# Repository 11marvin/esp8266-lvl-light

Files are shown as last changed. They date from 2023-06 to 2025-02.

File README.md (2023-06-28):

# ESP8266 LVL Light Control Board

This project contains the KiCad design files for a replacement control board used to control the LVL ceiling light (https://templates.blakadder.com/lvl_300.html) with additional features such as brightness adjustment, colour temperature control (CCT) and Wi-Fi connectivity. The board also includes provisions for connecting an I2C bus, a GPIO and power supply (3V3, GND).

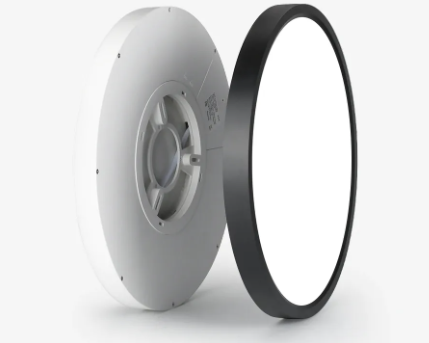
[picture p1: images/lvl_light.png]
LVL Ceiling Light


## Features

- Control LVL ceiling light using ESP8266-12F
- Adjust brightness and color temperature (CCT)
- Wi-Fi connectivity for remote control and automation
- I2C bus and GPIO for additional device integration

## Board

32 mm x 20 mm (without antenna overlap)

### Front
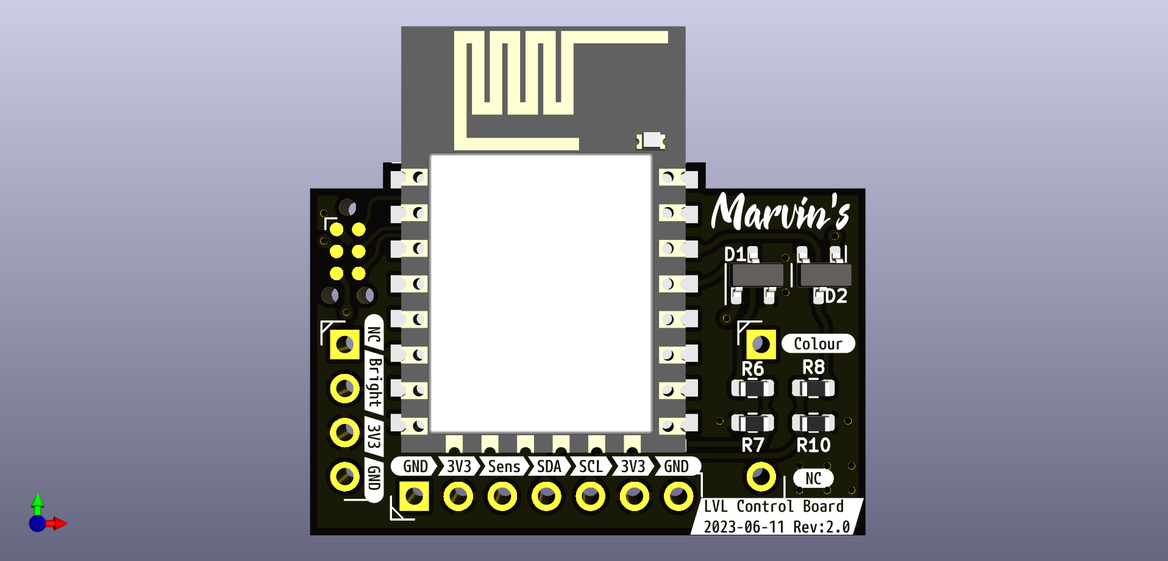
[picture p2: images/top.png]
Front side


### Back
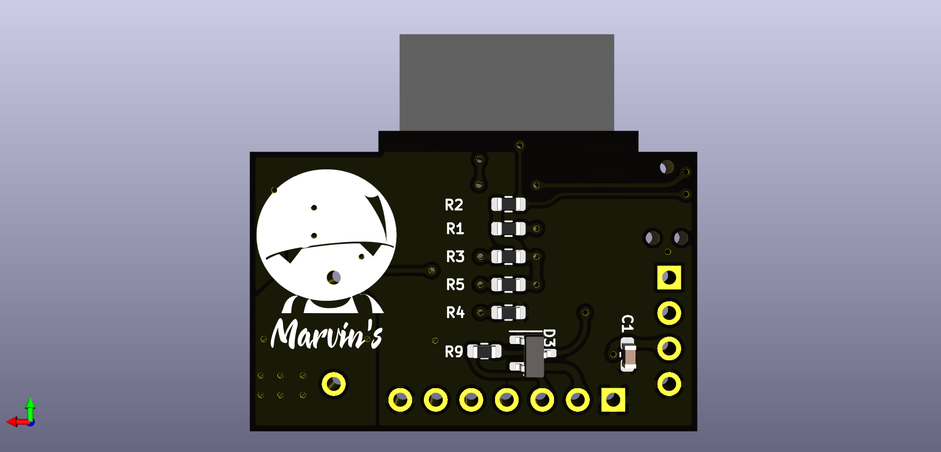
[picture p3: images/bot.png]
Back side


## Contributing

Contributions are welcome! If you find any issues or have suggestions for improvements, please open an issue or submit a pull request.

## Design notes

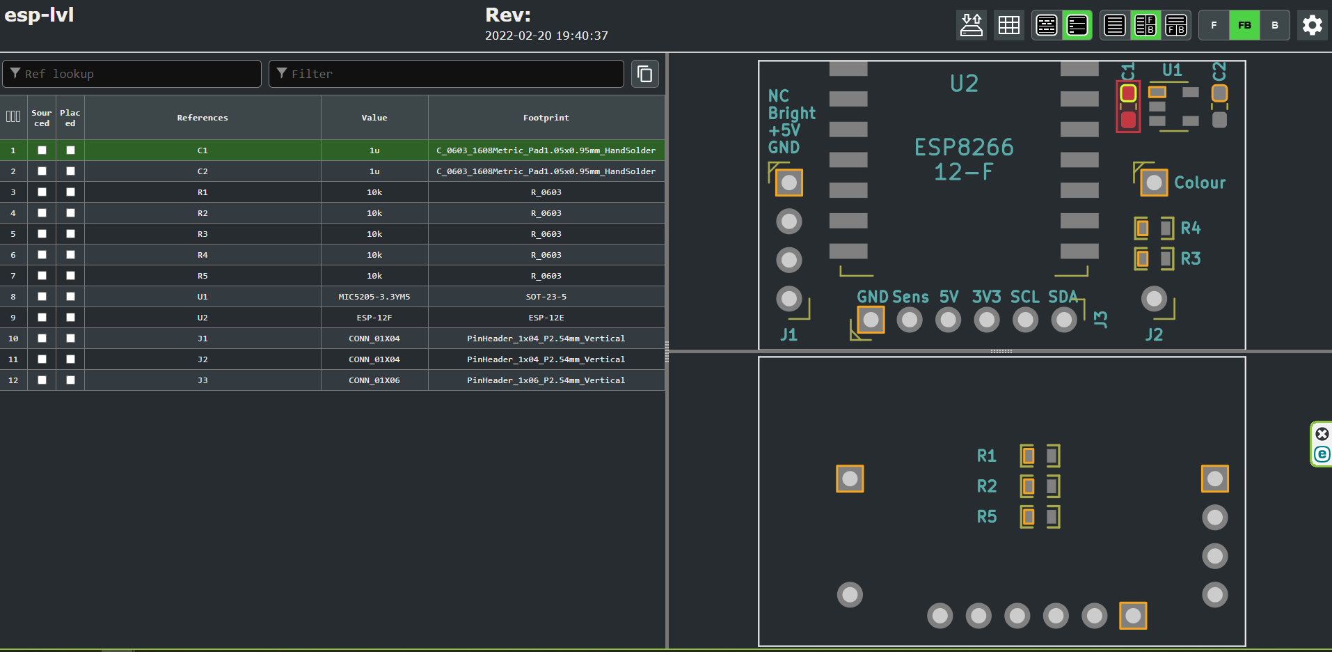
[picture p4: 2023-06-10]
Documentation/Board.png

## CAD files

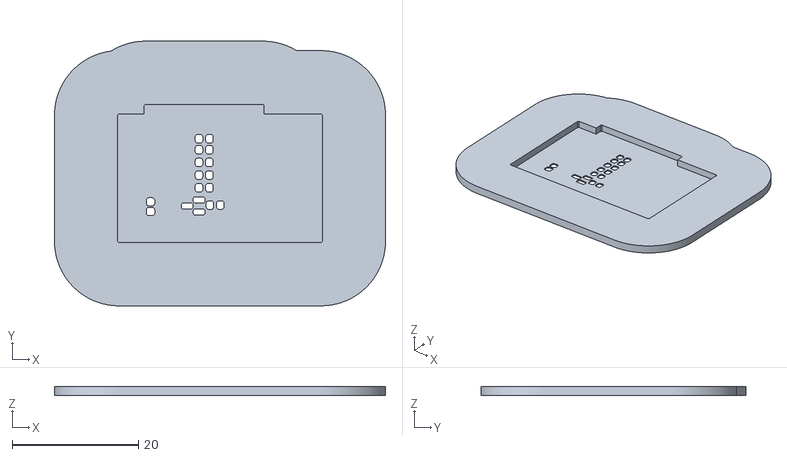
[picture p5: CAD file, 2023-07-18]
Fabrication/STL/bottomStencil.stl
52.4 x 41.9 x 1.50

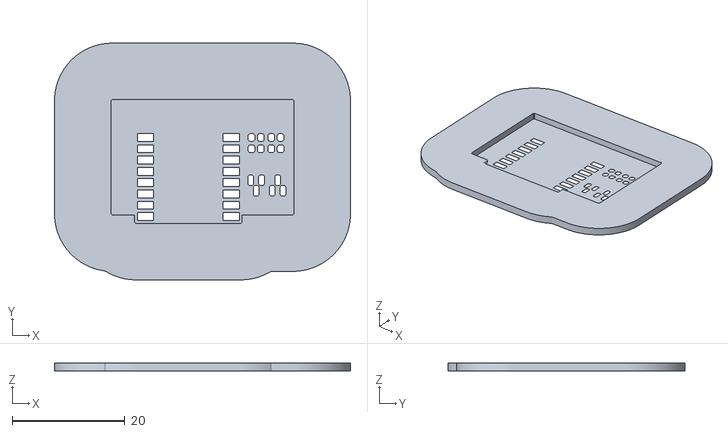
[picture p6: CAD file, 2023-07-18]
Fabrication/STL/topStencil.stl
52.4 x 41.9 x 1.50

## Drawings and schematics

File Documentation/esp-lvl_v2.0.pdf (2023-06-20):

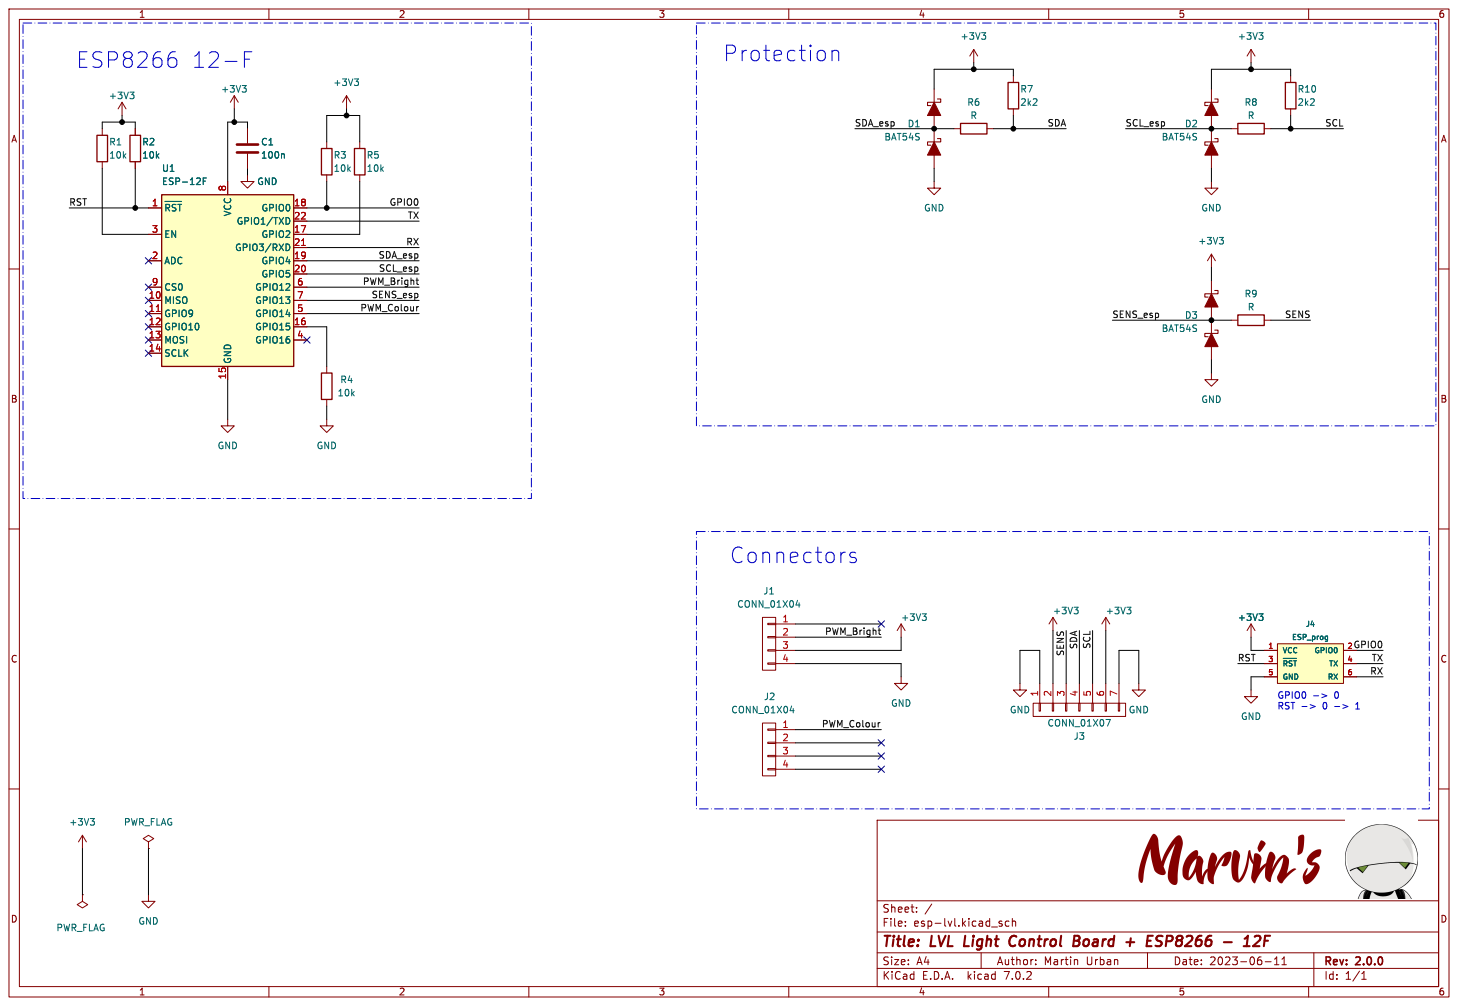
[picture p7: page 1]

Id: 1/1 Title: LVL Light Control Board + ESP8266 - 12F

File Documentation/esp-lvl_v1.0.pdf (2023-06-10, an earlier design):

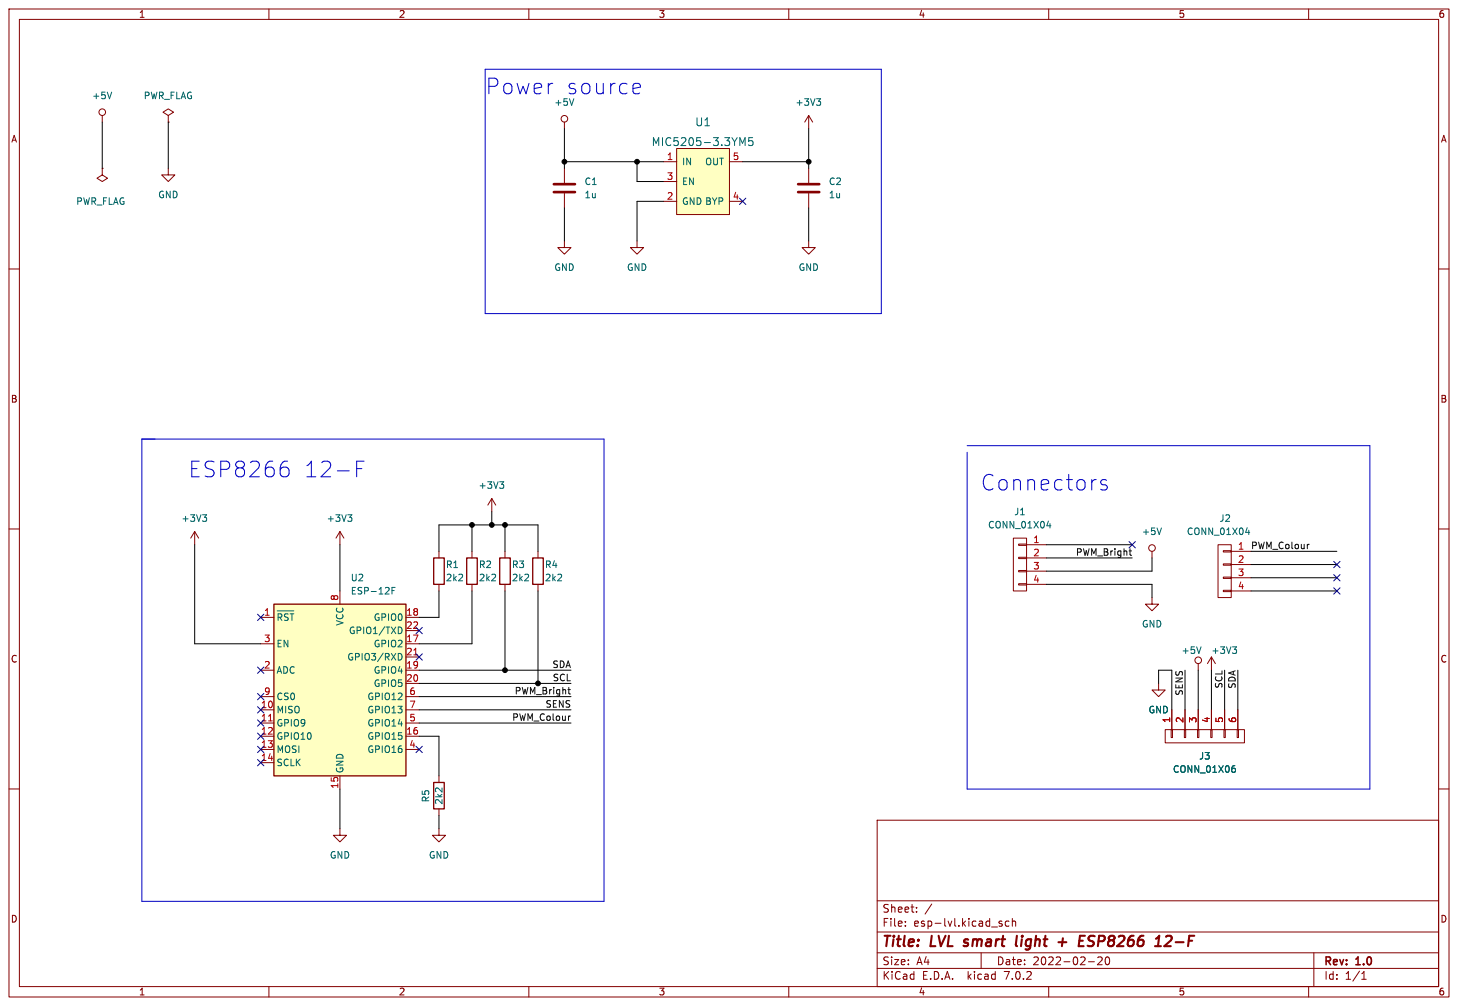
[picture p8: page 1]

Id: 1/1 Title: LVL smart light + ESP8266 12-F

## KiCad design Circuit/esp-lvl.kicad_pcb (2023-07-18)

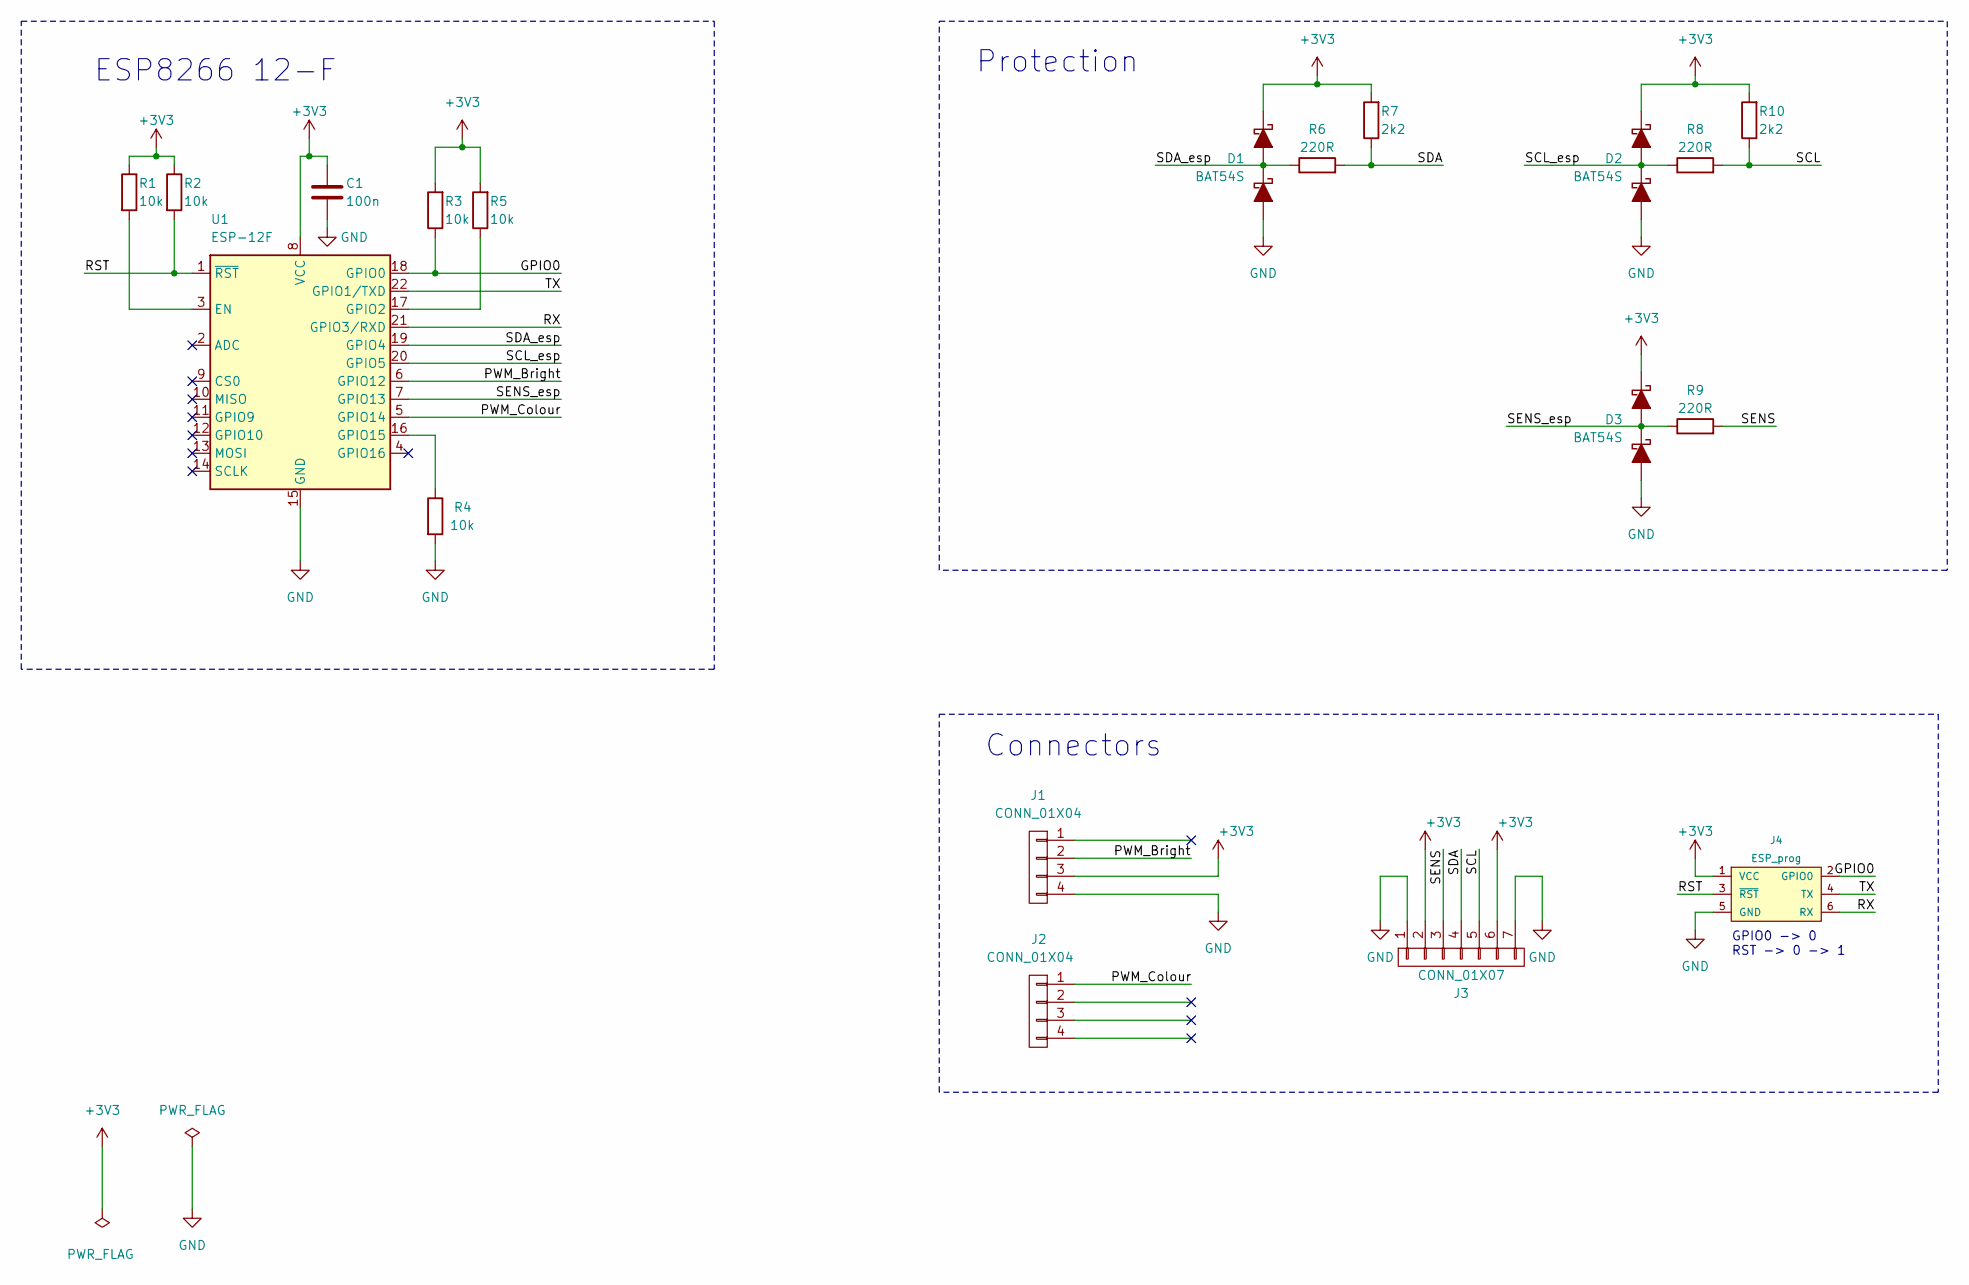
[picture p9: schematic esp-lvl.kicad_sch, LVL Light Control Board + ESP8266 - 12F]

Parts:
C1: 100n; C_0603_1608Metric
D1, D2, D3: BAT54S; SOT-23
J1, J2: CONN_01X04; PinHeader_1x04_P2.54mm_Vertical
J3: CONN_01X07; PinHeader_1x07_P2.54mm_Vertical
J4: ESP_prog; Tag-Connect_TC2030-IDC-NL
R1, R2, R3, R4, R5: 10k; R_0603_1608Metric
R6, R8, R9: 220R; R_0603_1608Metric
R7, R10: 2k2; R_0603_1608Metric
U1: ESP-12F; ESP-12E

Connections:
+3V3: C1.1, D1.2 (C), D2.2 (C), D3.2 (C), J1.3, J3.2, J3.6, J4.1 (VCC), R1.1, R2.1, R3.2, R5.2, R7.2, R10.2, U1.8 (VCC)
/GPIO0: J4.2 (GPIO0), R3.1, U1.18 (GPIO0)
/PWM_Bright: J1.2, U1.6 (GPIO12)
/PWM_Colour: J2.1, U1.5 (GPIO14)
/RST: J4.3 (~RST), R2.2, U1.1 (~RST)
/RX: J4.6 (RX), U1.21 (GPIO3/RXD)
/SCL: J3.5, R8.2, R10.1
/SCL_esp: D2.3 (C), R8.1, U1.20 (GPIO5)
/SDA: J3.4, R6.2, R7.1
/SDA_esp: D1.3 (C), R6.1, U1.19 (GPIO4)
/SENS: J3.3, R9.2
/SENS_esp: D3.3 (C), R9.1, U1.7 (GPIO13)
/TX: J4.4 (TX), U1.22 (GPIO1/TXD)
GND: C1.2, D1.1 (A), D2.1 (A), D3.1 (A), J1.4, J3.1, J3.7, J4.5 (GND), R4.2, U1.15 (GND)
unnamed: R1.2, U1.3 (EN)
unnamed: R5.1, U1.17 (GPIO2)
unnamed: R4.1, U1.16 (GPIO15)

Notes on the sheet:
Connectors
GPIO0 -> 0 RST -> 0 -> 1
Protection
ESP8266 12-F

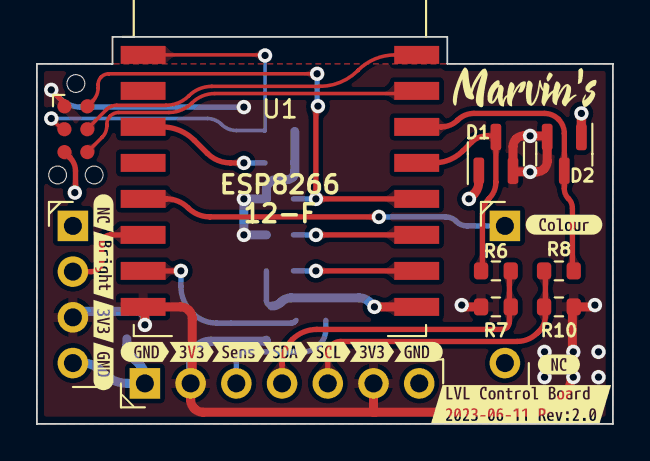
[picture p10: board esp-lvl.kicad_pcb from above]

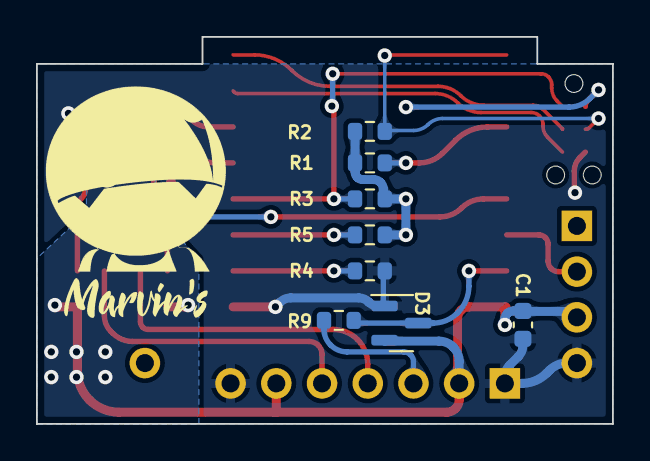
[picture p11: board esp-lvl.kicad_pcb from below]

Board: 2 copper layers, 32.0 x 21.5 mm, 35 parts (9 on the bottom side), 17 nets.

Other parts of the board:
kibuzzard-6485D4C1: G***; kibuzzard-6485D4C1
kibuzzard-6485EB90: G***; kibuzzard-6485EB90
kibuzzard-64859B50: G***; kibuzzard-64859B50
kibuzzard-648599E7: G***; kibuzzard-648599E7
kibuzzard-6485947F: G***; kibuzzard-6485947F
kibuzzard-6485998B: G***; kibuzzard-6485998B
kibuzzard-64859500, kibuzzard-64859500#2: G***; kibuzzard-64859500
kibuzzard-64859549: G***; kibuzzard-64859549
kibuzzard-64859551: G***; kibuzzard-64859551
kibuzzard-64859557: G***; kibuzzard-64859557
kibuzzard-64859561: G***; kibuzzard-64859561
kibuzzard-64859916: G***; kibuzzard-64859916
kibuzzard-64859921: G***; kibuzzard-64859921
kibuzzard-64859928: G***; kibuzzard-64859928
kibuzzard-64860007: G***; kibuzzard-64860007

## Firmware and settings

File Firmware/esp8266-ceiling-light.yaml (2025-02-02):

substitutions:
  devicename: "ceiling-light"
  friendly_name: "Ceiling Light"

esphome:
  platform: ESP8266
  board: esp12e

  name: ${devicename}
  friendly_name: ${friendly_name}
  name_add_mac_suffix: True

  comment: Dimmable ceiling light with CCT and motion detector.
  project:
    name: Marvin's.${friendly_name}
    version: "1.0.3"

  on_boot:
    - script.execute: offline_light

dashboard_import:
  package_import_url: github://11marvin/esp8266-lvl-light/Firmware/esp8266-ceiling-light.yaml@master

wifi:

  # Enable fallback hotspot (captive portal) in case wifi connection fails
  ap: {} # This spawns an AP with the device name and mac address with no password.

web_server:
  port: 80
  
captive_portal:

# Enable logging
logger:

# Enable Home Assistant API
api:

# Enable Home Assistant OTA
ota:
  platform: esphome


script:
  - id: offline_light
    mode: restart     # Light will be kept on during 10 minutes since
                      # the latest time the script is executed
    then:
      - light.turn_on:
          id: mylight 
          brightness: 90%
          color_temperature: 3900K
      - delay: 10 min
      - light.turn_off: mylight

sensor:
  - platform: wifi_signal
    name: WiFi Signal
    update_interval: 60s

binary_sensor:
  - platform: gpio
    id: motion
    pin:
      number: GPIO13
    name: motion
    device_class: motion
    on_press:
      - while:
          condition:
            binary_sensor.is_on: motion
          then:
            - if:
                condition:
                  not:
                    api.connected:
                then:
                  - script.execute: offline_light
            - delay: 1 min

switch:
  - platform: restart
    name: Restart
    
light:
  - platform: color_temperature
    id: mylight
    name: "Light"
    brightness: output_brightness
    color_temperature: output_temperature
    cold_white_color_temperature: 4600 K
    warm_white_color_temperature: 2800 K

  - platform: monochromatic
    name: "Notification LED"
    output: output_component1
    id: led
    
output:
  - platform: esp8266_pwm
    id: output_component1
    pin: GPIO2
    inverted: True
    
  - platform: esp8266_pwm
    id: output_brightness
    min_power: 0.06
    zero_means_zero: True
    pin: GPIO12
    inverted: False
    
  - platform: esp8266_pwm
    id: output_temperature
    pin: GPIO14
    inverted: True

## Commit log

2023-06-10 Files structure
    [esp-lvl-B_Cu.gbr, esp-lvl-B_Mask.gbr, esp-lvl-B_Silkscreen.gbr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]
2023-07-18 BOM updated
    [esp-lvl.kicad_pcb, esp-lvl.kicad_sch]
2023-07-18 add models for 3D printing of stencils
    [bottomStencil.stl, topStencil.stl]
2025-02-02 Removed debug settings for temperature and brightness
